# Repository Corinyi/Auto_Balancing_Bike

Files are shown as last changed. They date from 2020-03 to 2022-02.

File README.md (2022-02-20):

# Auto Balancing Bike
-------------------------
##스스로 균형을 잡고 컨트롤 할수 있는 자전거 로봇

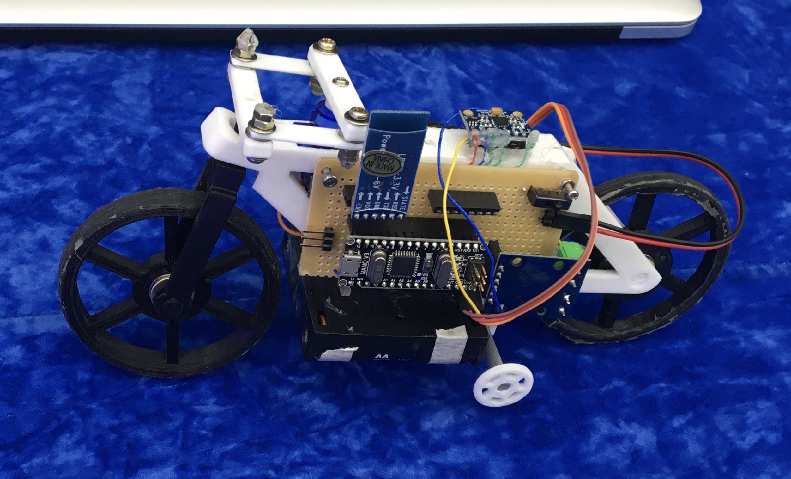
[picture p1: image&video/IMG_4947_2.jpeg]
Auto Balancing Bike


완성된 모습

[전시회 판넬 자전거팀.pdf](https://github.com/Corinyi/Auto_Balancing_Bike/files/8103481/default.pdf)

## 하드웨어 구성

*  사 용  부 품
>       아두이노 : Arduino Nano V3 (328)
>       기울기 및 자이로 센서 : MPU6050
>       블루투스 모듈 : HC-05
>       서보 모터 : SG90
>       DC 모터 : RoboRobo 200rpm  DC 모터(모터 RPM 높은 것으로 변경 요망)
>       전원 : 6V
>       프레임, 휠 : 3D 프린터로 제작
>       바퀴 : 실리콘 도포로 마찰력 극대화

## 소프트 웨어 구성

### 칼만 필터(Kalman Filter)
MPU6050의 결과값을 통해 기울어진 값을 받아온다. 이 때 충격이나 오차 등의 원인으로 결과값이 불균일하게 도출되는 경우가 있다. 소위 결과값이 '튄다'라고 한다.
갑작스러운 결과값의 방지하기 위해 칼만필터를 사용한다. 쉽게 말해 결과값 변화를 완충한다. 
위 프로젝트에서는 기울기 결과값의 변화를 완충하기 위해 아래 프로젝트를 참고하였다.

[MPU6050 칼만필터 적용](https://m.blog.naver.com/PostView.nhn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)

### P.I.D. 제어(Proportional-Integral-Differential control)
PID 제어는 출력값과 목표값의 차이를 계산하여서 피드백 제어하는 제어 기법 중 하나이다.
위 프로젝트에서는 서보모터를 이용하여서 자전거의 조향장치인 앞바퀴 핸들을 조정한다.
기준값인 수평 기울기 0도를 목표으로 하여서 출력값인 서보모터 기울기의 오차를 측정하고 서보 제어값을 변화시킨다.

[PID 제어](https://ko.wikipedia.org/wiki/PID_제어기)

> 첨부한 코드에는 PID 제어 항목이 들어가 있지 않다. 실제 전시에는 PID 제어가 적용된 코드를 사용하였지만 제작자의 불찰로 인해 코드가 유실되어, PID 제어를 제외한 코드로 출력된다.

이 PID 제어를 거치게 되면, 자전거 로봇이 수평 기울기 0도를 최대한 유지하며 이동할 수 있다.

### 블루투스 컨트롤(Bluetooth Control)
블루투스 컨트롤은 아두이노에 외부 장치를 이용해서 신호를 주는 방식의 일환이다.
위 프로젝트에서는 스마트폰을 이용하여서 자전거 로봇의 이동과 속도 조절을 제어하였다.
스마트폰 어플리케이션으로는 
[Arduino Bluetooth Controller](https://play.google.com/store/apps/details?id=com.giumig.apps.bluetoothserialmonitor&hl=en_US) 를 사용하였다.

콘솔모드에서 상하좌우에 해당하는 character를 설정할 수 있다. 이 설정된 문자가 아두이노에 들어갔을 때 모드의 역할을 하게 된다. 
이 모드 결정변수를 switch문에 적용하여 모드(이동 방향, 속도)를 결정하였다.
특히 좌우 운행은 PID 제어 기준값의 변경을 이용하였다.(ex. 좌측 운행은 기울기 기준값을 -15도로 설정하였다.)

## 개발 환경

MacOS Catalina, Version 10.15.1
Arduino Application, 1.8.1.1 

## 제작자

Corinyi and SIOR

Copyright @ 2019 Sungkyunkwan Institute of Robotics

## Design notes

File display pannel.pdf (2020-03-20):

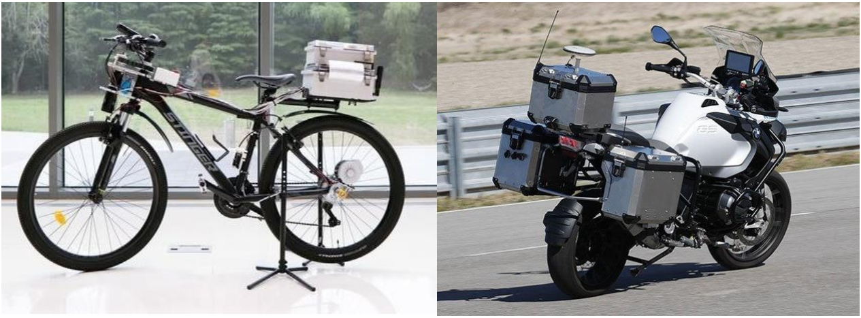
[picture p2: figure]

## ⚫ Kalman Filter

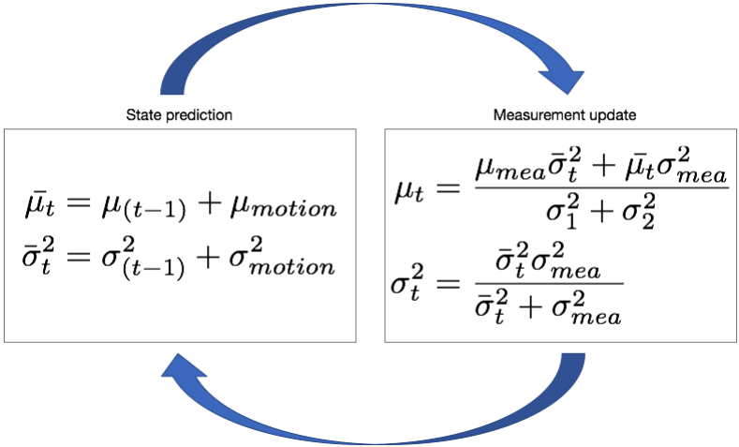
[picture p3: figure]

- 루프만 칼만이 1960년대 초 개발한 필터로 과거의 정보와 새로운 측정값을 사용하여 측정값에 포함된 잡음을 제거해 최적의 값을 추적하는 데 사용하는 알고리즘이다. 선형적 움직임을 갖는 대상에 재귀적으로 동작한다.

## ⚫ Arduino

# 이륜차 조향 매커니즘을 적용한 자전거 로봇

# Auto Balancing Bike

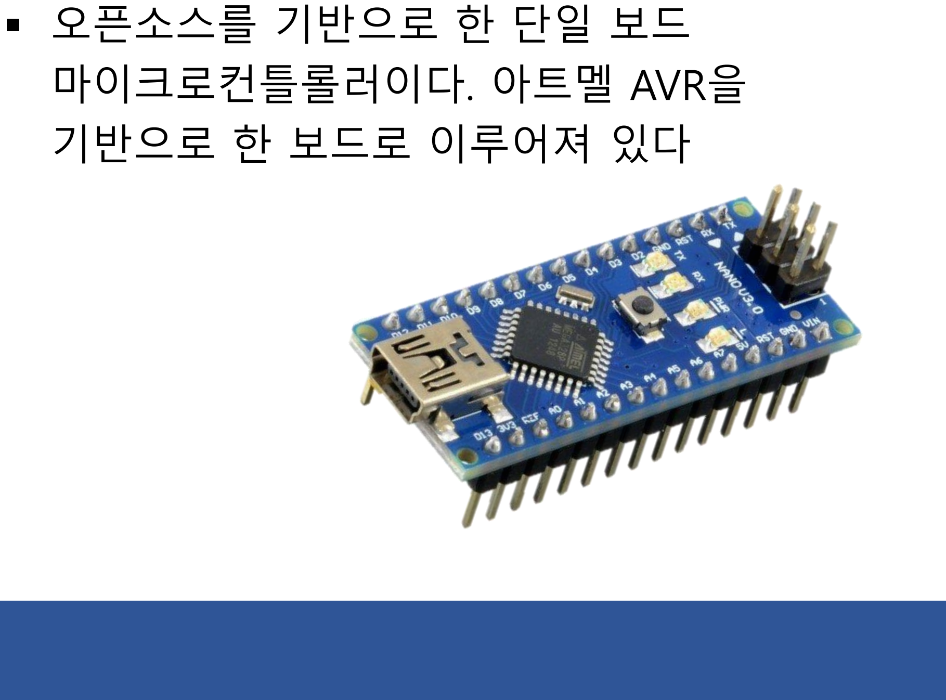
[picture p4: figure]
▪ 오픈소스를 기반으로 한 단일 보드 마이크로컨틀롤러이다. 아트멜 AVR을 기반으로 한 보드로 이루어져 있다
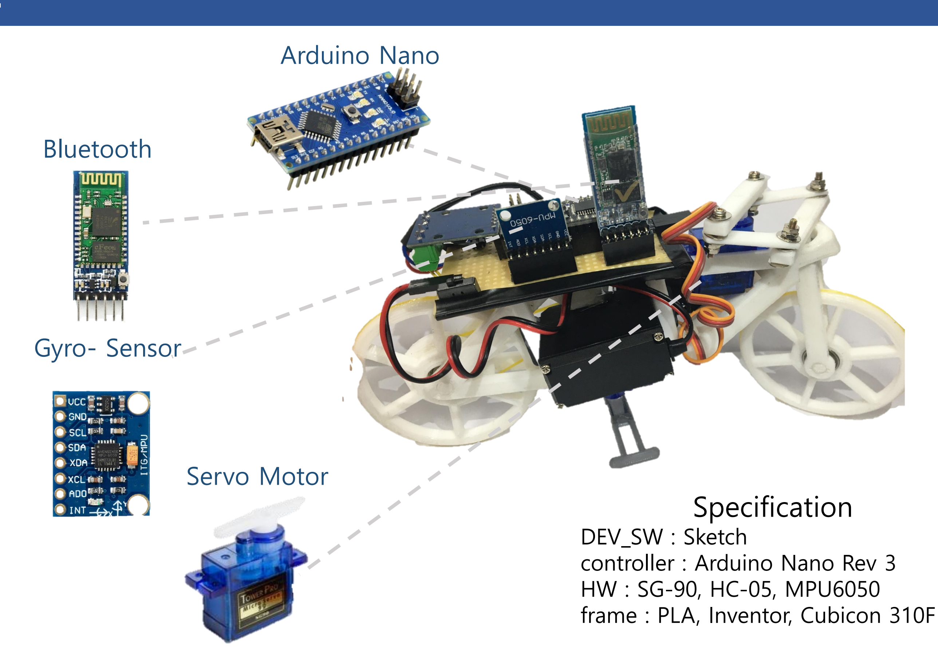
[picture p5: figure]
Arduino Nano; Gyro- Sensor; Servo Motor; Specification DEV_SW : Sketch controller : Arduino Nano Rev 3 HW : SG-90, HC-05, MPU6050 frame : PLA, Inventor, Cubicon 310F; Bluetooth
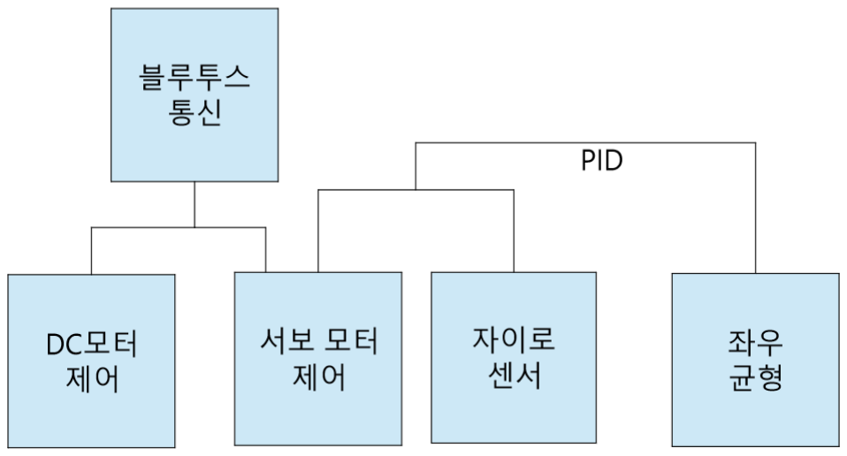
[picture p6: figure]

자율주행 이륜차로 발전하여, 사용자의 운전이 필요 없는 개인용 차량으로 사용 가능, 모빌리티 및 다양한 서비스에 적용 가능

팀명 : ABB 팀원 : 이윤서, 류호영, 채수권

## 작품 소개 (작품 소개, 배경, 설명 등등)

## ⚫ 자율 주행 자동차의 한계

- 고가의 개발 비용 및 유지 비용, 다수의 교통 음영 지대 발생

## ⚫ 자율주행 이륜차의 필요성

- 상대적 저가의 개발 비용 및 유지 비용,
교통 음영 지대 커버리지 우세

## ⚫ 모빌리티 산업의 발달

- 개인에게 신속하고 안전하게 접근하는 로봇 목표 인간의 자전거 조향 시스템 자동화 목표

## 사용 기술

### 1. 자율 주행 이륜구동 자동차

장애물 회피 및 네비게이션 기능을 추가하여 자율 주행 이륜차로 발전 가능하다. 자율주행 자동차에 비해 비용이 저렴하고 교통 음영 지대가 없어
사용자 친화적이다. 목적지를 입력하면 장애물을
회피하면서 최적의 경로로 주행한다. 복잡한
도심지역 및 밀집된 주택가에서 그 효용 가치가
매우 크다.

### 2. 모빌리티 산업 로봇

복잡한 도심지역 및 주택가 등에서 음식 배달 및 P2P 물건 거래에서 사용될 수 있는 자율 주행 이륜구동 자동차 로봇으로 발전 가능하다.
자동차에 비해 교통 음영 지대 접근성이 우수하고 경제적이다. 특히 골목길 음식 배달에서 자동차에 비해 우수한 경쟁력을 가진다.

## 작품 구조

## 발전 가능성

2019 SIOR 작품 전시회

### 3. 주택지역 경비

경찰차가 다니기 힘든 주택가 및 교통 음영
지대에 자율주행 무인 이륜구동 경비 로봇을
설치하여 상대적으로 적발되기 힘든 범죄 상황을
확인하고 용의자 검거에 도움을 줄 수 있다.
포스텍 송영운 학생이 개발한 자율주행 자전거 | BMW 자율주행 오토바이

## ⚫ 자이로 센서

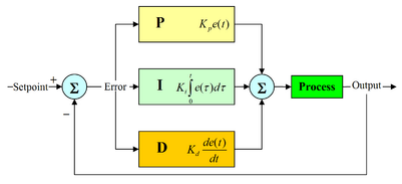
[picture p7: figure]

- 회전하는 물체의 회전힘을 전기적 신호로
변환하여 각속도를 계산한다.

## ⚫ PID제어

- 제어하고자 하는 대상의 출력값을 측정하여 이를 원하고자 하는 참조값과 비교하여 오차를 계산하고, 오차값을 이용하여 제어에 필요한 제어값을 구하는 구조이다.

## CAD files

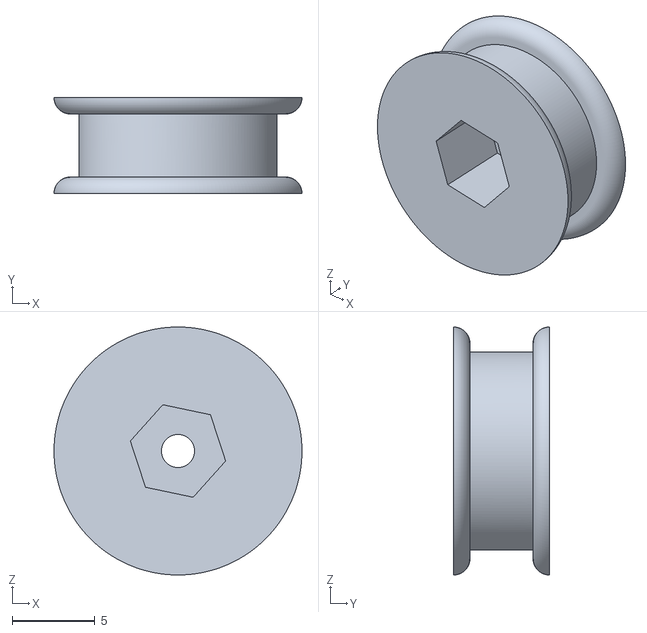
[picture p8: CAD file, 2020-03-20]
stl file/motor gear.stl
15.0 x 5.80 x 15.0

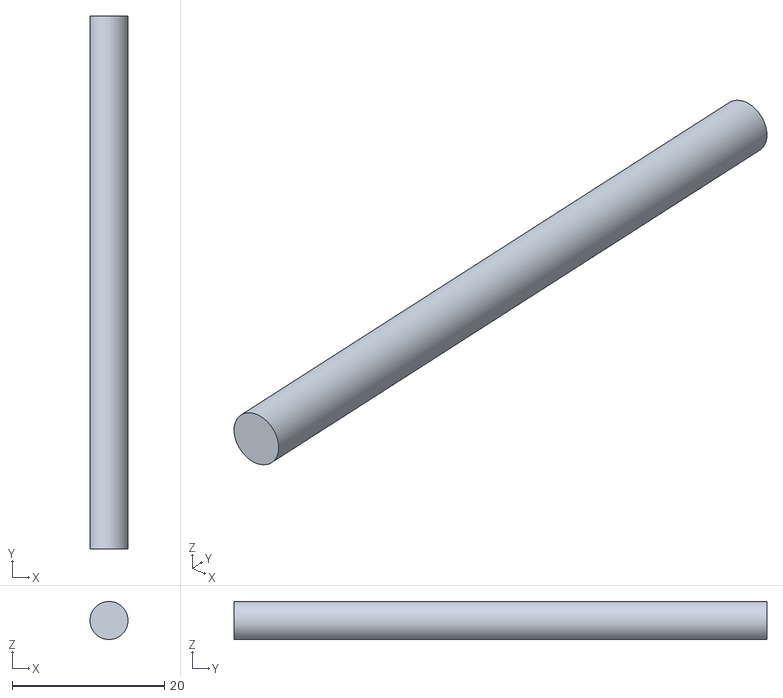
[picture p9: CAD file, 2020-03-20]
stl file/choook3.stl
5.00 x 70.0 x 5.00

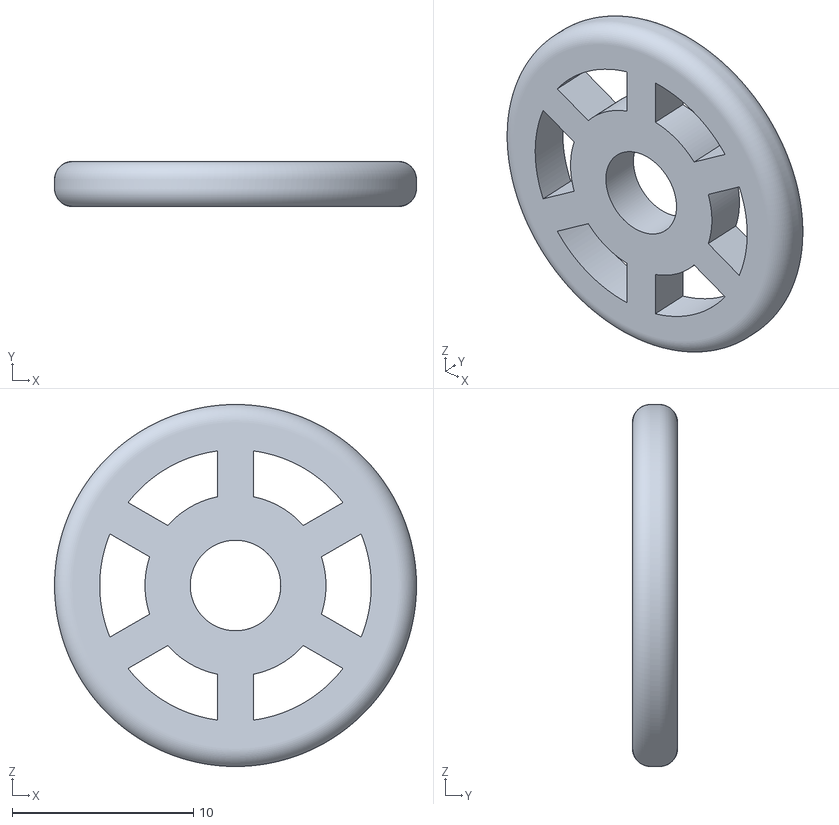
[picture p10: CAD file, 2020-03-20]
stl file/wheelbojo.stl
20.0 x 2.50 x 20.0

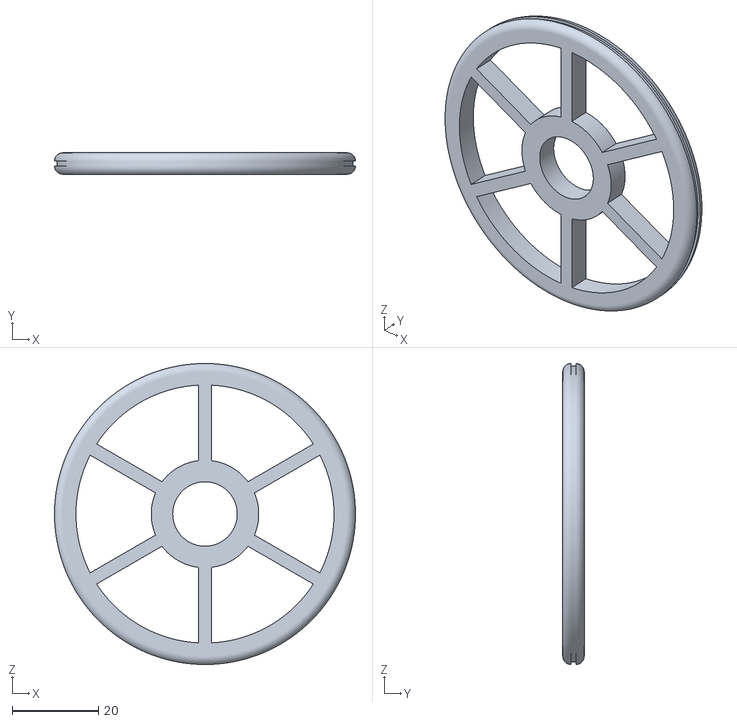
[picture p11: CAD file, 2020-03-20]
stl file/앞바퀴.stl
70.0 x 5.00 x 70.0

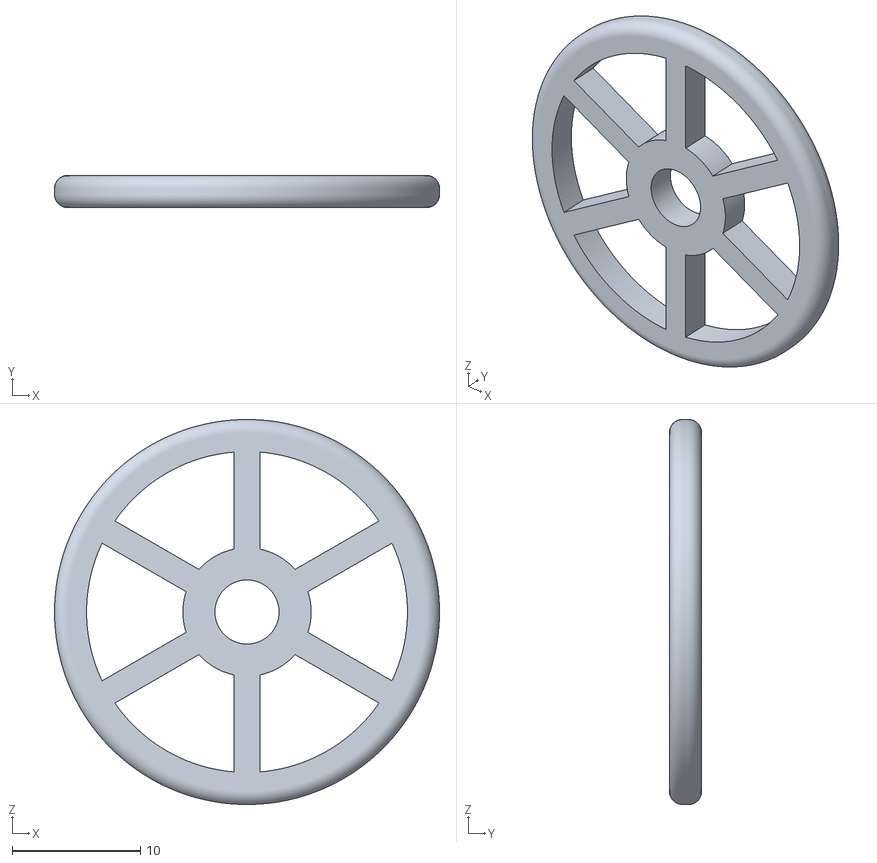
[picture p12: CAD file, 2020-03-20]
stl file/bojobachi.stl
30.0 x 2.50 x 30.0

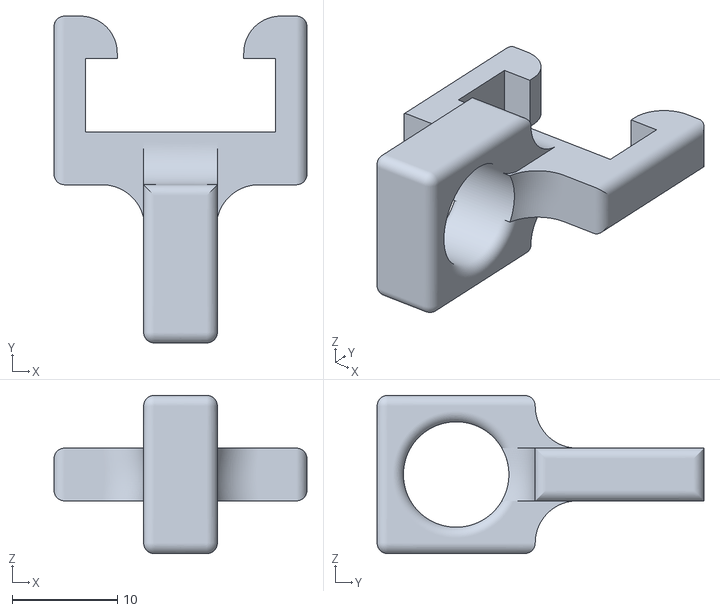
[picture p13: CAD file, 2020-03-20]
stl file/보조바퀴 축.stl
24.0 x 31.0 x 15.0

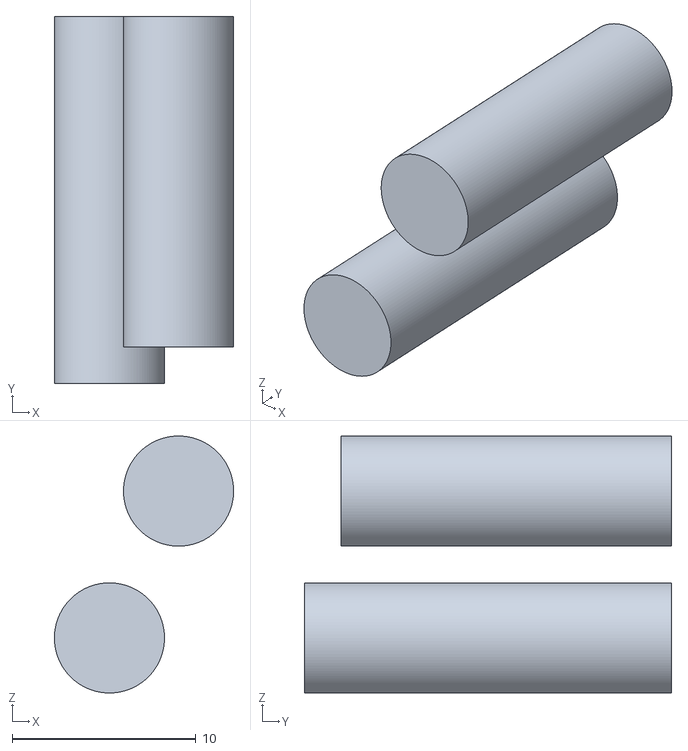
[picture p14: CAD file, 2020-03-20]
stl file/chook final.stl
9.76 x 20.0 x 14.0

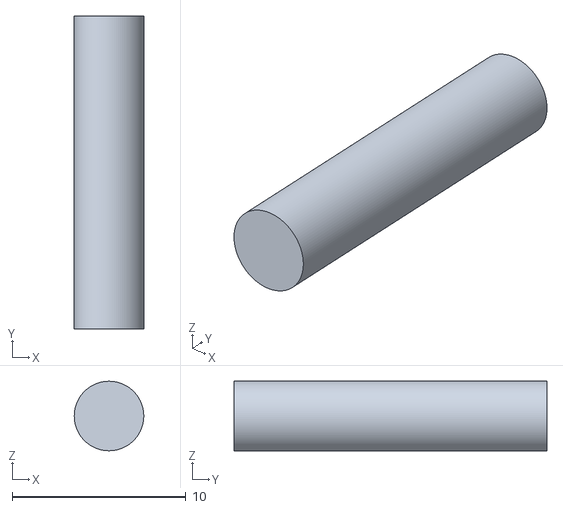
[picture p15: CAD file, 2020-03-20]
stl file/chuuk.stl
4.00 x 18.0 x 4.00

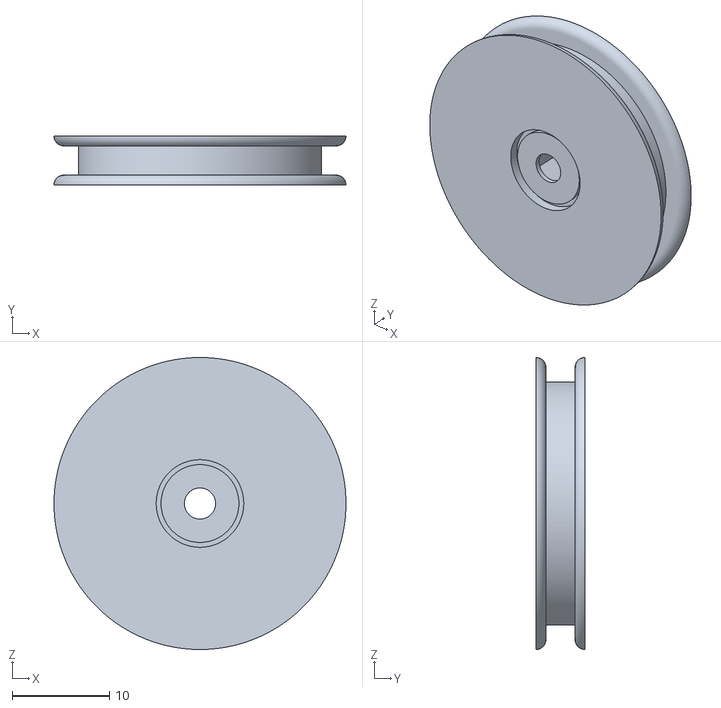
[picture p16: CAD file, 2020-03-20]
stl file/모터기어.stl
30.0 x 5.00 x 30.0

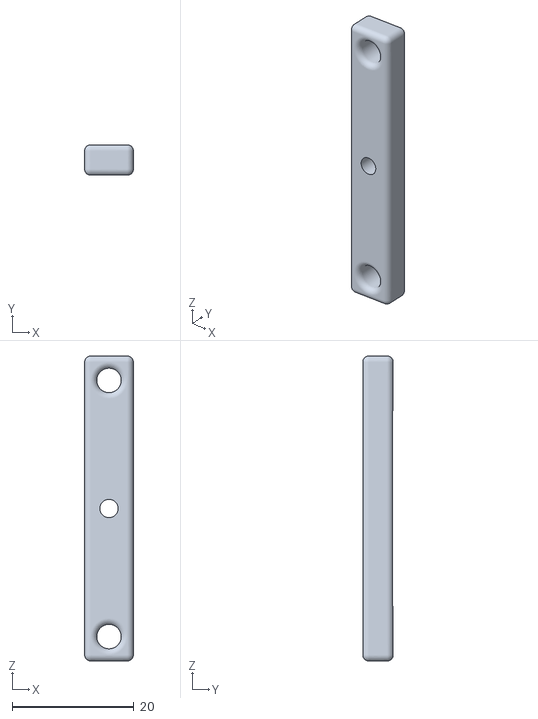
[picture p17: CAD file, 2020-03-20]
stl file/핸들서보.stl
8.00 x 5.00 x 50.0

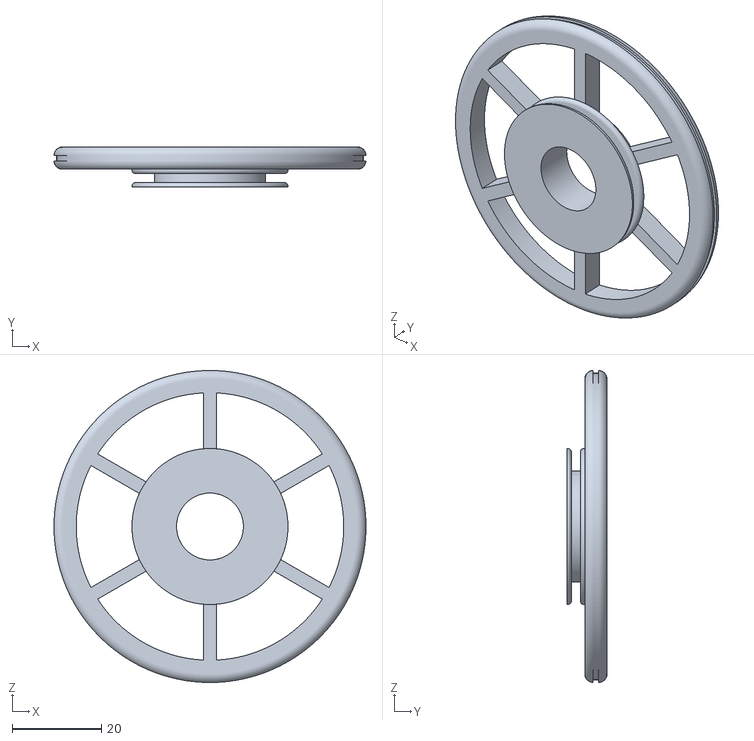
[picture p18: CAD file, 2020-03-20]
stl file/뒷바퀴.stl
70.0 x 9.00 x 70.0

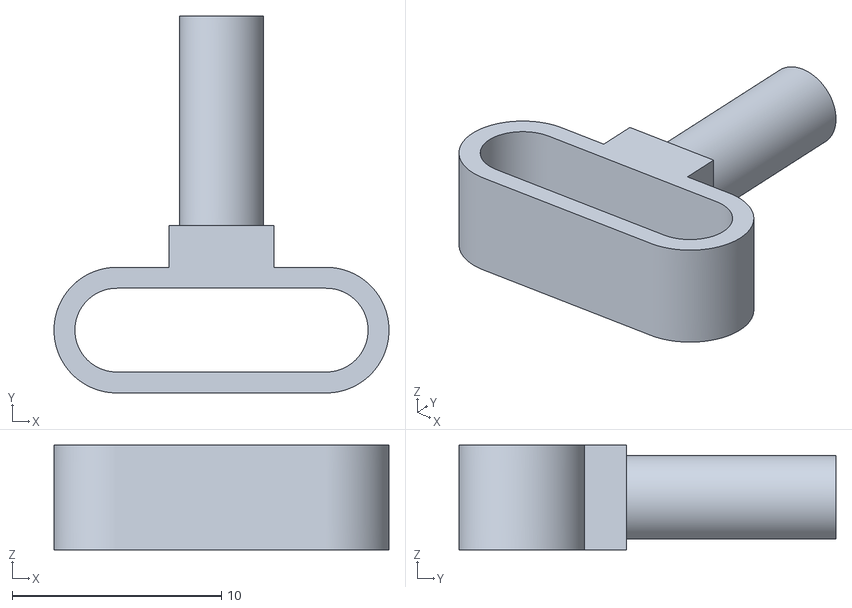
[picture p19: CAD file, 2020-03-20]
stl file/부품1.stl
16.0 x 18.0 x 5.00

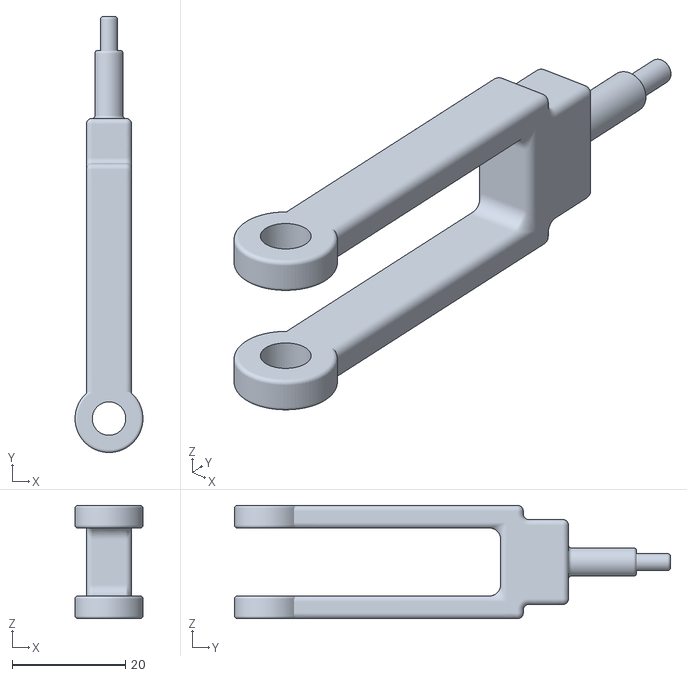
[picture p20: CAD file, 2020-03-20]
stl file/front stand.stl
12.0 x 77.0 x 20.0

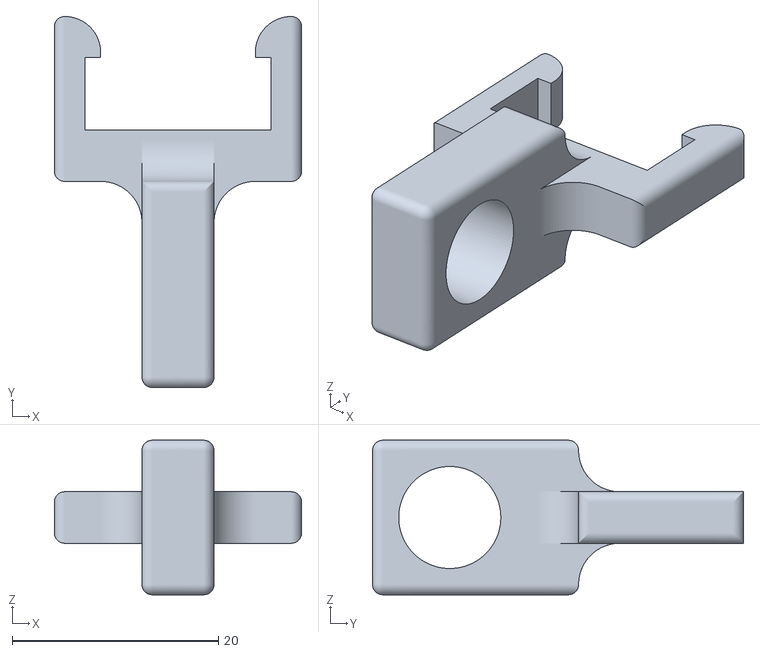
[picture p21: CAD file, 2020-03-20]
stl file/bojo final.stl
24.0 x 36.0 x 15.0

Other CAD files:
stl file/rear tire.stl
stl file/handle gear.stl
stl file/bal.stl
inventor file/bal.ipt
inventor file/chook.ipt
inventor file/choook3.ipt
inventor file/gojung.ipt
inventor file/handle gear.ipt
inventor file/motor gear.ipt
inventor file/뒷바퀴.ipt
inventor file/뒷바퀴2.ipt
inventor file/모터기어.ipt
inventor file/보조바퀴 축.ipt
inventor file/보조바퀴.ipt
inventor file/부품1.ipt
inventor file/부품2.ipt
inventor file/부품26.ipt
inventor file/앞바퀴.ipt
inventor file/앞바퀴2.ipt
inventor file/앞바퀴스탠드.ipt
inventor file/조립품1.iam
inventor file/조립품4.iam
inventor file/핸들.ipt
inventor file/핸들서보.ipt
stl file/front tire.stl
stl file/gojung.stl
stl file/핸들.stl

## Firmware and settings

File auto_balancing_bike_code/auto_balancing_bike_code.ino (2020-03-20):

#include <Wire.h>
#include <Servo.h>  
#include <SoftwareSerial.h>
SoftwareSerial bt(7,6);
#define mpu_add 0x68  //mpu6050 address

class kalman {
  public :
    double getkalman(double acc, double gyro, double dt) {
      //project the state ahead
      angle += dt * (gyro - bias) ;

      //Project the error covariance ahead
      P[0][0] += dt * (dt * P[1][1] - P[0][1] - P[1][0] + Q_angle) ;
      P[0][1] -= dt * P[1][1] ;
      P[1][0] -= dt * P[1][1] ;
      P[1][1] += Q_gyro * dt ;

      //Compute the Kalman gain
      double S = P[0][0] + R_measure ;
      K[0] = P[0][0] / S ;
      K[1] = P[1][0] / S ;

      //Update estimate with measurement z
      double y = acc - angle ;
      angle += K[0] * y ;
      bias += K[1] * y ;

      //Update the error covariance
      double P_temp[2] = {P[0][0], P[0][1]} ;
      P[0][0] -= K[0] * P_temp[0] ;
      P[0][1] -= K[0] * P_temp[1] ;
      P[1][0] -= K[1] * P_temp[0] ;
      P[1][1] -= K[1] * P_temp[1] ;

      return angle ;
    } ;
    void init(double angle, double gyro, double measure) {
      Q_angle = angle ;
      Q_gyro = gyro ;
      R_measure = measure ;

      angle = 0 ;
      bias = 0 ;

      P[0][0] = 0 ;
      P[0][1] = 0 ;
      P[1][0] = 0 ;
      P[1][1] = 0 ;
    } ;
    double getvar(int num) {
      switch (num) {
        case 0 :
          return Q_angle ;
          break ;
        case 1 :
          return Q_gyro ;
          break ;
        case 2 :
          return R_measure ;
          break ;
      }
    } ;
  private :
    double Q_angle, Q_gyro, R_measure ;
    double angle, bias ;
    double P[2][2], K[2] ;
} ;

kalman kal ;

long ac_x, ac_y, ac_z, gy_x, gy_y, gy_z ;

double deg, dgz_z ;
double dt ;
uint32_t pasttime ;
Servo sg90;   
Servo sg902;      
int servo_pin = 9;
int servo_pin2 = 8;
int serval=0;


int a;
int b;
int *p=&b;
char bts='x';



void setup() {
  // put your setup code here, to run once:
  pinMode(4, OUTPUT);       // Motor B 방향설정1
  pinMode(5, OUTPUT);

  Serial.begin(9600) ;
  sg90.attach ( servo_pin );
  sg902.attach(servo_pin2);
  Wire.begin() ;
  bt.begin(9600);
  Wire.beginTransmission(mpu_add) ;
  Wire.write(0x6B) ;
  Wire.write(0) ;
  Wire.endTransmission(true) ;
  kal.init(0.001, 0.003, 0.03) ;  //init kalman filter
  
  
}

void loop() {
  // put your main code here, to run repeatedly:
        
  Wire.beginTransmission(mpu_add) ; //get acc data
  Wire.write(0x3B) ;
  Wire.endTransmission(false) ;
  Wire.requestFrom(mpu_add, 6, true) ;
  ac_x = Wire.read() << 8 | Wire.read() ;
  ac_y = Wire.read() << 8 | Wire.read() ;
  ac_z = Wire.read() << 8 | Wire.read() ;

  Wire.beginTransmission(mpu_add) ; //get gyro data
  Wire.write(0x43) ;
  Wire.endTransmission(false) ;
  Wire.requestFrom(mpu_add, 6, true) ;
  gy_x = Wire.read() << 8 | Wire.read() ;
  gy_y = Wire.read() << 8 | Wire.read() ;
  gy_z = Wire.read() << 8 | Wire.read() ;

  deg = atan2(ac_x, ac_z) * 180 / PI ;  //acc data to degree data
  dgz_z = gy_z / 131. ;  //gyro output to

  dt = 0.3;//((double)(micros() - pasttime) / 1000000)*3;
  pasttime = micros();  //convert output to understandable data

  double val = kal.getkalman(deg, dgz_z, dt) ;  //get kalman data
  /*
  serval = map (val, -50, 50, 0, 80) ;
  Serial.print("kalman degree") ;
  */
  //Serial.println (val);


  bts =bt.read();

  if(bts == 'a'){
    a=0;
    b=250;

    }
  if(bts == 'b'){
    a=-10;
    b=150;
 
    }
  if(bts == 'c'){
    a=+10;
    b=150;

    }
  if(bts == 'd'){
    a=0;
    b=130;
    }
  if(bts == 'x'){
    for(int i = 90; i > 0;i--) {
      analogWrite(4,1.5*i);
      sg902.write(100-i);
      delay (10);
    }
    b=0;
    }
  if(bts == 'o'){
    a=0;

    for(int i=0;i<150;i++){
      analogWrite(4,i);
      delay(20);
    }
        sg902.write (10);
    delay(40);
    b=150;
   }



  if(val>100){
    sg90.write (65+a);
    delay(50);
    }
  else if(val<80){
    sg90.write (25+a);
    delay(50);
    }
  else if(val>=80 && val<=100){
    sg90.write(45+a);
    delay(50);
  }

  analogWrite(4, 0+b);     
  analogWrite(5, 0);   

}
